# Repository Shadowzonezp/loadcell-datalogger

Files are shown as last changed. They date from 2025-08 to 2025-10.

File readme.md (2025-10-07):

# StaticTesterDatalogger

A WiFi-enabled datalogger for load cell measurements using ESP32, HX711, and SD card storage.  
Provides a web interface for calibration, recording, and downloading measurement files.

## Features

- **Load Cell Support:** Uses HX711 ADC for precise force measurements.
- **Web Interface:** Start/stop logging, tare, calibrate, and download recordings from any browser.
- **SD Card Storage:** Saves measurements as CSV files in `/recordings` folder.
- **WiFi Manager:** Easily configure WiFi credentials via captive portal.
- **NTP Time:** Filenames use network time for easy identification.
- **Calibration:** Two-step calibration via web interface.
- **File Download:** Download CSV recordings directly from the web UI.

## Hardware

- ESP32 board
- HX711 load cell amplifier
- Load cell sensor
- SD card module (SPI)
- Optional: External power supply for load cell

## Usage

1. **Wiring:**  
   - Connect HX711 to ESP32 pins (default: DOUT=17, SCK=16).
   - Connect SD card module to SPI pins (default: SCK=15, MISO=32, MOSI=33, CS=-1).

2. **Flash the firmware:**  
   - Open `StaticFile.ino` in Arduino IDE or PlatformIO.
   - Install required libraries:  
     - `ESPAsyncWebServer`, `WiFiManager`, `HX711_ADC`, `NTPClient`, `SD`, `SPI`
   - Upload to ESP32.

3. **Connect to WiFi:**  
   - On first boot, ESP32 creates a WiFi access point.
   - Connect and configure WiFi via captive portal.

4. **Web Interface:**  
   - Access the device via its IP address (or `esp32dl.local` if mDNS is supported).
   - Use the interface to tare, calibrate, start/stop logging, and download files.

5. **Recording:**  
   - Press "Start" to begin logging.
   - Press "Stop" to end and save data to SD card.
   - Download CSV files from the "Recordings" section.

## File Structure

- `StaticFile.ino` — Main firmware for ESP32
- `HTML/index.html` — Main web interface
- `HTML/calibration.html` — Calibration page

## API Endpoints

- `/tare` (POST): Tare the load cell
- `/calibrate` (GET): Calibrate with known mass (`?mass=VALUE`)
- `/start` (POST): Start logging
- `/stop` (POST): Stop logging and save data
- `/list?dir=/recordings` (GET): List recordings as JSON
- `/recordings/<filename>` (GET): Download CSV file

## Example CSV Output

```
timestamp,value
12345,0.123456
12456,0.234567
...
```

## License

Apache 2.0
Copyright 2025 Ferran Espigares Garcia 

---

**Note:**  
For best results, use a genuine ESP32, quality SD card, and ensure stable power for the load cell and HX711.

Files for a 3d rocket test stand are included in "3d-stand-files"

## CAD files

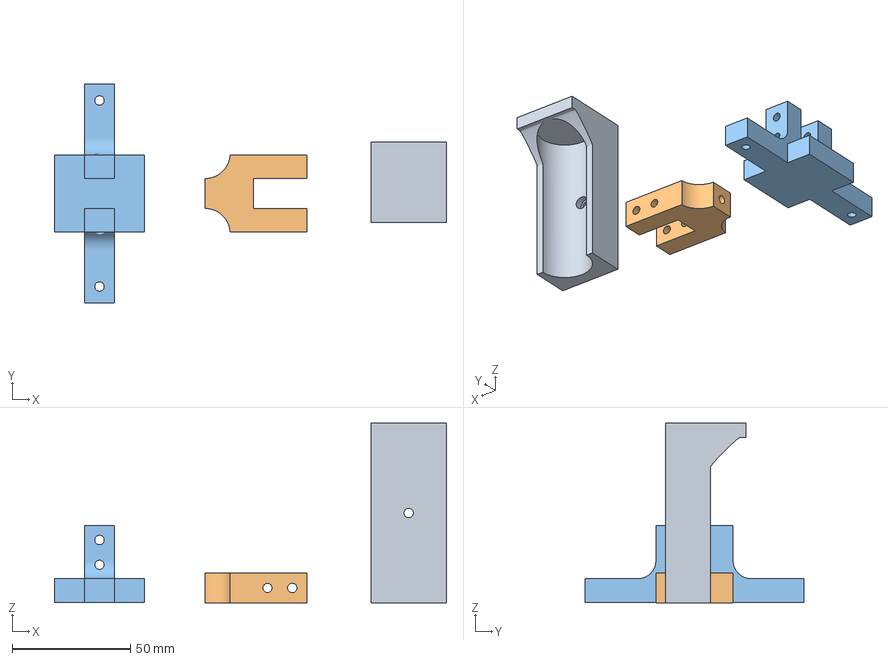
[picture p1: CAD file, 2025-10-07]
3d-stand-files/Load cell things v9.3mf
165.7 x 92.7 x 76.0 mm

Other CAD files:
3d-stand-files/Load cell stand.f3d

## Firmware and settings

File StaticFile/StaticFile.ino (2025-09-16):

// SPDX-License-Identifier: LGPL-3.0-or-later
// Copyright 2016-2025 Hristo Gochkov, Mathieu Carbou, Emil Muratov

//
// Shows how to serve a static file
//

#include <Arduino.h>
#include <AsyncTCP.h>
#include <WiFi.h>
#include <WiFiManager.h> // https://github.com/tzapu/WiFiManager
#include <ESPAsyncWebServer.h>
#include <ESPmDNS.h>
//#include <LittleFS.h>
#include "FS.h"
#include "SD.h"
#include "SPI.h"
#include <NTPClient.h>
#include <WiFiUdp.h>
#include <Preferences.h>
#include <HX711_ADC.h>

//pins:
const int HX711_dout = 17; //mcu > HX711 dout pin
const int HX711_sck = 16; //mcu > HX711 sck pin

//HX711 constructor:
HX711_ADC LoadCell(HX711_dout, HX711_sck);

Preferences preferences;
/*
Uncomment and set up if you want to use custom pins for the SPI communication
*/
#define REASSIGN_PINS
int sck = 15;
int miso = 32;
int mosi = 33;
int cs = -1;

int endmillis = 0;
int startmillis = 0;

bool loggingActive = false;

unsigned long t = 0;

static AsyncWebServer server(80);

WiFiUDP ntpUDP;
NTPClient timeClient(ntpUDP, "2.europe.pool.ntp.org",3600*2); // 3600*2 is for timezone GMT+2

void initSDCard(){
#ifdef REASSIGN_PINS
  SPI.begin(sck, miso, mosi, cs);
  if (!SD.begin(cs)) {
#else
  if (!SD.begin()) {
#endif
    Serial.println("Card Mount Failed");
    return;
  }
  uint8_t cardType = SD.cardType();

  if (cardType == CARD_NONE) {
    Serial.println("ERROR: No SD card attached");
    return;
  }

  Serial.print("SD Card Type: ");
  if (cardType == CARD_MMC) {
    Serial.println("MMC");
  } else if (cardType == CARD_SD) {
    Serial.println("SDSC");
  } else if (cardType == CARD_SDHC) {
    Serial.println("SDHC");
  } else {
    Serial.println("UNKNOWN");
  }
  uint64_t cardSize = SD.cardSize() / (1024 * 1024);
  Serial.printf("SD Card Size: %lluMB\n", cardSize);
}

void listDir(fs::FS &fs, const char *dirname, uint8_t levels) {
  Serial.printf("Listing directory: %s\n", dirname);

  File root = fs.open(dirname);
  if (!root) {
    Serial.println("Failed to open directory");
    return;
  }
  if (!root.isDirectory()) {
    Serial.println("Not a directory");
    return;
  }

  File file = root.openNextFile();
  while (file) {
    if (file.isDirectory()) {
      Serial.print("  DIR : ");
      Serial.println(file.name());
      if (levels) {
        listDir(fs, file.path(), levels - 1);
      }
    } else {
      Serial.print("  FILE: ");
      Serial.print(file.name());
      Serial.print("  SIZE: ");
      Serial.println(file.size());
    }
    file = root.openNextFile();
  }
}

void tare(AsyncWebServerRequest *request){
  Serial.println("called tare");
  // display params
  LoadCell.update();
  LoadCell.tareNoDelay();
  boolean _resume = false;
  while (_resume == false) {
    LoadCell.update();
    if (LoadCell.getTareStatus() == true) {
      Serial.println("Tare complete");
      _resume = true;
    }
  }
  request->send(200, "text/html", "ok" );
}

void hometare(AsyncWebServerRequest *request){
  Serial.println("called hometare");
  unsigned long stabilizingtime = 2000; // preciscion right after power-up can be improved by adding a few seconds of stabilizing time
  boolean _tare = true; //set this to false if you don't want tare to be performed in the next step
  LoadCell.start(stabilizingtime, _tare);
  request->send(200, "text/html", "ok" );
}

void calibrate(AsyncWebServerRequest *request){
  float known_mass = 0;
  Serial.println("called calibrate");
  size_t count = request->params();
  for (size_t i = 0; i < count; i++) {
    const AsyncWebParameter* p = request->getParam(i);
    Serial.printf("PARAM[%u]: %s = %s\n", i, p->name().c_str(), p->value().c_str());
  }
  const AsyncWebParameter* param = request->getParam("mass");
  if (param != nullptr){
    //preferences.putUInt("calvalue", param->value().toInt());
    known_mass = param->value().toFloat();
    Serial.println(known_mass);
  }
  LoadCell.refreshDataSet(); //refresh the dataset to be sure that the known mass is measured correct
  float newCalibrationValue = LoadCell.getNewCalibration(known_mass); //get the new calibration value
  Serial.println(newCalibrationValue);
  preferences.putFloat("calvalue", newCalibrationValue);
  request->redirect( "/index.html" );
}

void start(AsyncWebServerRequest *request) {
  loggingActive = true;
  startmillis = millis();
  Serial.println("Logging started");
  request->send(200, "text/html", "ok");
}

// Buffer for storing load cell readings (15KB for ESP32)
#define BUFFER_SIZE 15000
struct LoadCellSample {
    unsigned long timestamp;
    float value;
};
constexpr size_t SAMPLE_SIZE = sizeof(LoadCellSample); // 8 bytes per sample (4+4)
constexpr size_t MAX_SAMPLES = BUFFER_SIZE / SAMPLE_SIZE;
LoadCellSample sampleBuffer[MAX_SAMPLES];
volatile size_t sampleCount = 0;

void printSampleBuffer() {
    Serial.println("=== Sample Buffer Contents ===");
    for (size_t i = 0; i < sampleCount; i++) {
        Serial.print("Sample ");
        Serial.print(i);
        Serial.print(": millis=");
        Serial.print(sampleBuffer[i].timestamp);
        Serial.print(", value=");
        Serial.println(sampleBuffer[i].value, 6);
    }
    Serial.println("=== End of Buffer ===");
}

void stop(AsyncWebServerRequest *request) {
  loggingActive = false;
  endmillis = millis();
  Serial.println("Logging stopped");
  int milliselapsed = endmillis - startmillis;
  Serial.println("Duration in millis:");
  Serial.println(milliselapsed);

  // Print buffer contents for debugging
  printSampleBuffer();

  // ==== Save buffer to SD card ====
  // Create "recordings" directory if it doesn't exist
  if (!SD.exists("/recordings")) {
    SD.mkdir("/recordings");
  }

  // Use NTP time at start of recording for filename
  time_t startEpoch = timeClient.getEpochTime() - ((millis() - startmillis) / 1000);
  struct tm *tmstruct = gmtime(&startEpoch);
  char timeString[32];
  strftime(timeString, sizeof(timeString), "%Y%m%d_%H%M%S", tmstruct);

  char filename[64];
  snprintf(filename, sizeof(filename), "/recordings/rec_%s.csv", timeString);

  File file = SD.open(filename, FILE_WRITE);
  if (!file) {
    Serial.println("Failed to open file for writing!");
  } else {
    // Write CSV header
    file.println("timestamp,value");
    // Write all samples
    for (size_t i = 0; i < sampleCount; i++) {
      file.print(sampleBuffer[i].timestamp);
      file.print(",");
      file.println(sampleBuffer[i].value, 6);
    }
    file.close();
    Serial.print("Saved buffer to SD: ");
    Serial.println(filename);
  }

  // Optionally clear the buffer after saving
  sampleCount = 0;

  request->send(200, "text/html", "ok");
}

void setup() {
  Serial.begin(115200);
// WiFi.mode(WIFI_STA); // explicitly set mode, esp defaults to STA+AP
  // it is a good practice to make sure your code sets wifi mode how you want it.
  // put your setup code here, to run once:
  Serial.begin(115200);
  initSDCard();
  listDir(SD, "/", 0);
    
  //WiFiManager, Local intialization. Once its business is done, there is no need to keep it around
  WiFiManager wm;

  // reset settings - wipe stored credentials for testing
  // these are stored by the esp library
  // wm.resetSettings();

  // Automatically connect using saved credentials,
  // if connection fails, it starts an access point with the specified name ( "AutoConnectAP"),
  // if empty will auto generate SSID, if password is blank it will be anonymous AP (wm.autoConnect())
  // then goes into a blocking loop awaiting configuration and will return success result

  bool res;
  // res = wm.autoConnect(); // auto generated AP name from chipid
  // res = wm.autoConnect("AutoConnectAP"); // anonymous ap
  res = wm.autoConnect("sigmaaccespoint","n0maswifi.1"); // password protected ap

  if(!res) {
      Serial.println("Failed to connect");
      // ESP.restart();
  } 
  else {
      //if you get here you have connected to the WiFi    
      Serial.println("connected...yeey :)");
  }
  // Set up mDNS responder:
  // - first argument is the domain name, in this example
  //   the fully-qualified domain name is "esp32.local"
  // - second argument is the IP address to advertise
  //   we send our IP address on the WiFi network
  if (!MDNS.begin("esp32dl")) {
    Serial.println("Error setting up MDNS responder!");
    while (1) {
      delay(1000);
    }
  }

  Serial.println("mDNS responder started");

  MDNS.addService("http", "tcp", 80);

//#if SOC_WIFI_SUPPORTED || CONFIG_ESP_WIFI_REMOTE_ENABLED || LT_ARD_HAS_WIFI
  //WiFi.mode(WIFI_AP);
  //WiFi.softAP("esp_captive");
//#endif

  // curl -v http://192.168.4.1/
  server.on("/", HTTP_GET, [](AsyncWebServerRequest *request) {
    request->redirect("/index.html");
  });
  // curl -v http://192.168.4.1/index.html
  server.serveStatic("/", SD, "/");
  server.serveStatic("/recordings", SD, "/recordings");

  preferences.begin("datalogger", false);
  float calvalue = preferences.getFloat("calvalue", 0);
  Serial.println("current calibration value:");
  Serial.println(calvalue);
  LoadCell.begin();
  
  //LoadCell.setReverseOutput(); //uncomment to turn a negative output value to positive
  unsigned long stabilizingtime = 2000; // preciscion right after power-up can be improved by adding a few seconds of stabilizing time
  boolean _tare = true; //set this to false if you don't want tare to be performed in the next step
  LoadCell.start(stabilizingtime, _tare);
  if (LoadCell.getTareTimeoutFlag() || LoadCell.getSignalTimeoutFlag()) {
    Serial.println("Timeout, check MCU>HX711 wiring and pin designations");
    while (1);
  }
  else {
    LoadCell.setCalFactor(calvalue); // user set calibration value (float), initial value 1.0 may be used for this sketch
    Serial.println("Startup is complete");
  }
  while (!LoadCell.update());

  server.on("/tare", HTTP_POST, tare);
  server.on("/hometare", HTTP_POST, hometare);
  server.on("/calibrate", HTTP_GET, calibrate);
  server.on("/start", HTTP_POST, start);
  server.on("/stop", HTTP_POST, stop);

  // Add this handler to your setup() in StaticFile.ino to serve the file list as JSON
  server.on("/list", HTTP_GET, [](AsyncWebServerRequest *request){
    String dir = "/";
    if (request->hasParam("dir")) dir = request->getParam("dir")->value();
    File root = SD.open(dir);
    if (!root || !root.isDirectory()) {
      request->send(404, "application/json", "[]");
      return;
    }
    String output = "[";
    File file = root.openNextFile();
    bool first = true;
    while (file) {
      if (!file.isDirectory()) {
        if (!first) output += ",";
        String fname = String(file.name());
        String url = fname;
        // Ensure the URL is correct for /recordings
        if (dir.endsWith("/")) {
          if (!fname.startsWith(dir)) url = dir + fname;
        } else {
          if (!fname.startsWith(dir + "/")) url = dir + "/" + fname;
        }
        output += "{\"name\":\"";
        output += fname.substring(fname.lastIndexOf('/') + 1);
        output += "\",\"url\":\"";
        output += url;
        output += "\"}";
        first = false;
      }
      file = root.openNextFile();
    }
    output += "]";
    request->send(200, "application/json", output);
  });

  server.begin();
  timeClient.begin();
}

// not needed
void loop() {
    timeClient.update();

    // Only read/loadcell and print if logging is active
    static boolean newDataReady = 0;
    const int serialPrintInterval = 0;
    static unsigned long t = 0;

    if (loggingActive) {
        if (LoadCell.update()) newDataReady = true;
        if (newDataReady) {
            if (millis() > t + serialPrintInterval) {
                float i = LoadCell.getData();
                Serial.print("Load_cell output val: ");
                Serial.println(i);
                // Save to buffer if space available
                if (sampleCount < MAX_SAMPLES) {
                    sampleBuffer[sampleCount].timestamp = millis();
                    sampleBuffer[sampleCount].value = i;
                    sampleCount++;
                }
                newDataReady = 0;
                t = millis();
            }
        }
    }

    delay(10);
}

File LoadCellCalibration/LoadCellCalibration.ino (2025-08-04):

/*
   -------------------------------------------------------------------------------------
   HX711_ADC
   Arduino library for HX711 24-Bit Analog-to-Digital Converter for Weight Scales
   Olav Kallhovd sept2017
   -------------------------------------------------------------------------------------
*/

/*
   This example file shows how to calibrate the load cell and optionally store the calibration
   value in EEPROM, and also how to change the value manually.
   The result value can then later be included in your project sketch or fetched from EEPROM.

   To implement calibration in your project sketch the simplified procedure is as follow:
       LoadCell.tare();
       //place known mass
       LoadCell.refreshDataSet();
       float newCalibrationValue = LoadCell.getNewCalibration(known_mass);
*/

#include <HX711_ADC.h>
#if defined(ESP8266)|| defined(ESP32) || defined(AVR)
#include <EEPROM.h>
#endif

//pins:
const int HX711_dout = 17; //mcu > HX711 dout pin
const int HX711_sck = 16; //mcu > HX711 sck pin

//HX711 constructor:
HX711_ADC LoadCell(HX711_dout, HX711_sck);

const int calVal_eepromAdress = 0;
unsigned long t = 0;

void setup() {
  Serial.begin(57600); delay(10);
  Serial.println();
  Serial.println("Starting...");

  LoadCell.begin();
  //LoadCell.setReverseOutput(); //uncomment to turn a negative output value to positive
  unsigned long stabilizingtime = 2000; // preciscion right after power-up can be improved by adding a few seconds of stabilizing time
  boolean _tare = true; //set this to false if you don't want tare to be performed in the next step
  LoadCell.start(stabilizingtime, _tare);
  if (LoadCell.getTareTimeoutFlag() || LoadCell.getSignalTimeoutFlag()) {
    Serial.println("Timeout, check MCU>HX711 wiring and pin designations");
    while (1);
  }
  else {
    LoadCell.setCalFactor(1.0); // user set calibration value (float), initial value 1.0 may be used for this sketch
    Serial.println("Startup is complete");
  }
  while (!LoadCell.update());
  calibrate(); //start calibration procedure
}

void loop() {
  static boolean newDataReady = 0;
  const int serialPrintInterval = 0; //increase value to slow down serial print activity

  // check for new data/start next conversion:
  if (LoadCell.update()) newDataReady = true;

  // get smoothed value from the dataset:
  if (newDataReady) {
    if (millis() > t + serialPrintInterval) {
      float i = LoadCell.getData();
      Serial.print("Load_cell output val: ");
      Serial.println(i);
      newDataReady = 0;
      t = millis();
    }
  }

  // receive command from serial terminal
  if (Serial.available() > 0) {
    char inByte = Serial.read();
    if (inByte == 't') LoadCell.tareNoDelay(); //tare
    else if (inByte == 'r') calibrate(); //calibrate
    else if (inByte == 'c') changeSavedCalFactor(); //edit calibration value manually
  }

  // check if last tare operation is complete
  if (LoadCell.getTareStatus() == true) {
    Serial.println("Tare complete");
  }

}

void calibrate() {
  Serial.println("***");
  Serial.println("Start calibration:");
  Serial.println("Place the load cell an a level stable surface.");
  Serial.println("Remove any load applied to the load cell.");
  Serial.println("Send 't' from serial monitor to set the tare offset.");

  boolean _resume = false;
  while (_resume == false) {
    LoadCell.update();
    if (Serial.available() > 0) {
      if (Serial.available() > 0) {
        char inByte = Serial.read();
        if (inByte == 't') LoadCell.tareNoDelay();
      }
    }
    if (LoadCell.getTareStatus() == true) {
      Serial.println("Tare complete");
      _resume = true;
    }
  }

  Serial.println("Now, place your known mass on the loadcell.");
  Serial.println("Then send the weight of this mass (i.e. 100.0) from serial monitor.");

  float known_mass = 0;
  _resume = false;
  while (_resume == false) {
    LoadCell.update();
    if (Serial.available() > 0) {
      known_mass = Serial.parseFloat();
      if (known_mass != 0) {
        Serial.print("Known mass is: ");
        Serial.println(known_mass);
        _resume = true;
      }
    }
  }

  LoadCell.refreshDataSet(); //refresh the dataset to be sure that the known mass is measured correct
  float newCalibrationValue = LoadCell.getNewCalibration(known_mass); //get the new calibration value

  Serial.print("New calibration value has been set to: ");
  Serial.print(newCalibrationValue);
  Serial.println(", use this as calibration value (calFactor) in your project sketch.");
  Serial.print("Save this value to EEPROM adress ");
  Serial.print(calVal_eepromAdress);
  Serial.println("? y/n");

  _resume = false;
  while (_resume == false) {
    if (Serial.available() > 0) {
      char inByte = Serial.read();
      if (inByte == 'y') {
#if defined(ESP8266)|| defined(ESP32)
        EEPROM.begin(512);
#endif
        EEPROM.put(calVal_eepromAdress, newCalibrationValue);
#if defined(ESP8266)|| defined(ESP32)
        EEPROM.commit();
#endif
        EEPROM.get(calVal_eepromAdress, newCalibrationValue);
        Serial.print("Value ");
        Serial.print(newCalibrationValue);
        Serial.print(" saved to EEPROM address: ");
        Serial.println(calVal_eepromAdress);
        _resume = true;

      }
      else if (inByte == 'n') {
        Serial.println("Value not saved to EEPROM");
        _resume = true;
      }
    }
  }

  Serial.println("End calibration");
  Serial.println("***");
  Serial.println("To re-calibrate, send 'r' from serial monitor.");
  Serial.println("For manual edit of the calibration value, send 'c' from serial monitor.");
  Serial.println("***");
}
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

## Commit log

2025-08-02 Created calibration webpage
2025-08-02 Fixes to tare endpoint
    [StaticFile.ino]
2025-08-02 Syntax fixing on endpoints
    [StaticFile.ino]
2025-08-02 Calvalue now saves to EEPROM, index and calibration htmls almost finished. Missing SD writing and downloading
    [StaticFile.ino]
2025-08-04 Implemented hometare and loadcell calibration + calibration value saving via preferences
2025-08-06 The code now reads form the loadcell and prints to serial, fixed problems with crashes due to watchdog, void start is now non-blocking and loadcell reading code is now moved to void loop
    [StaticFile.ino]
2025-08-07 Final version, implemented 15KB buffer on the ESP32's ram for temporal storage of the loadcell output, when stop is called the buffer gets saved in a CSV file on the SD with the date and time as file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
2025-10-07 Added stand 3d files
    [Load cell stand.f3d, Load cell things v9.3mf]
